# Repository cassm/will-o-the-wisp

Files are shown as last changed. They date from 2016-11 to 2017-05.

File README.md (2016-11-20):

Will-o-the-wisp
===============

60 4-channel (rgbww) SK6812 LEDs arranged over 12 pentagonal PCBs in a pentagonal dodecahedron, controlled by a teensy 3.X.
---------------------------------------------

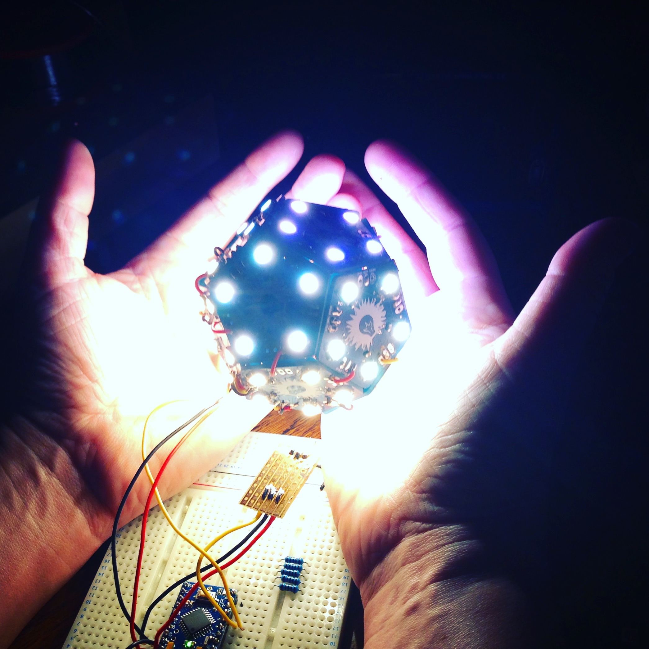
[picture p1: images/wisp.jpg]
Hands for scale Assembled example

[Photo Credit: Dee Ruane](https://www.instagram.com/everythinglightsup/)

Assembly notes:
--------------

- Each PCB has one input port and four output ports. Obviously the order and orientation in which they are wired up is critical, as co-ordinate calculation is done by static array lookup. I have not yet produced a set of instructions which represent how to assemble them in the order assumed by the software.

- I strongly advise against trying to get the firmware to compile on an arduino, as the full firmware relies on several large lookup tables being kept in memory. The code is written on the assumption that it will be run on something with at least as much capacity as a teensy 3

- You may notice that the current version of the PCBs have 6 leds one, rather than the stated 5. This is because I revised the design to give higher resolution for spacial patterns prior to learning that the fadecandy dithering routine supports a maximum of 64 leds in a string, and I have the intention of hacking in a cut-down version of fadecandy in order to support temporal dithering. However, the 64 pixel limit is a timing constraint, and is based on the assumption of 3 channels. As we are using 4 channels, this may imply a limit of (64*3 / 4 =) 48 LEDs per lantern, unless we split 3 DMA channels over 2 lanterns, which will involve much more wiring and anyway it's all very complicated and I don't want to think about it right now, but that's why.

- note that the Teensy has a logic voltage level of 3v3 and the pixels have a voltage level of 5v. I found that it mostly worked without shifting the logic level, but it was more prone to glitching. For this reason, I recommend the use of a logic level converter.

- When you're testing the module, I strongly recommend using some kind of diffuser, otherwise you'll end up with a bunch of things which look like QR codes in your vision, and that can't be good for you.

- The script which generates the palettes takes R8G8B8 encoded windows bitmaps, and requires python 3, scipy, numpy, and pillow. I intend to shortly add more interpolation options and make it way less hacky.

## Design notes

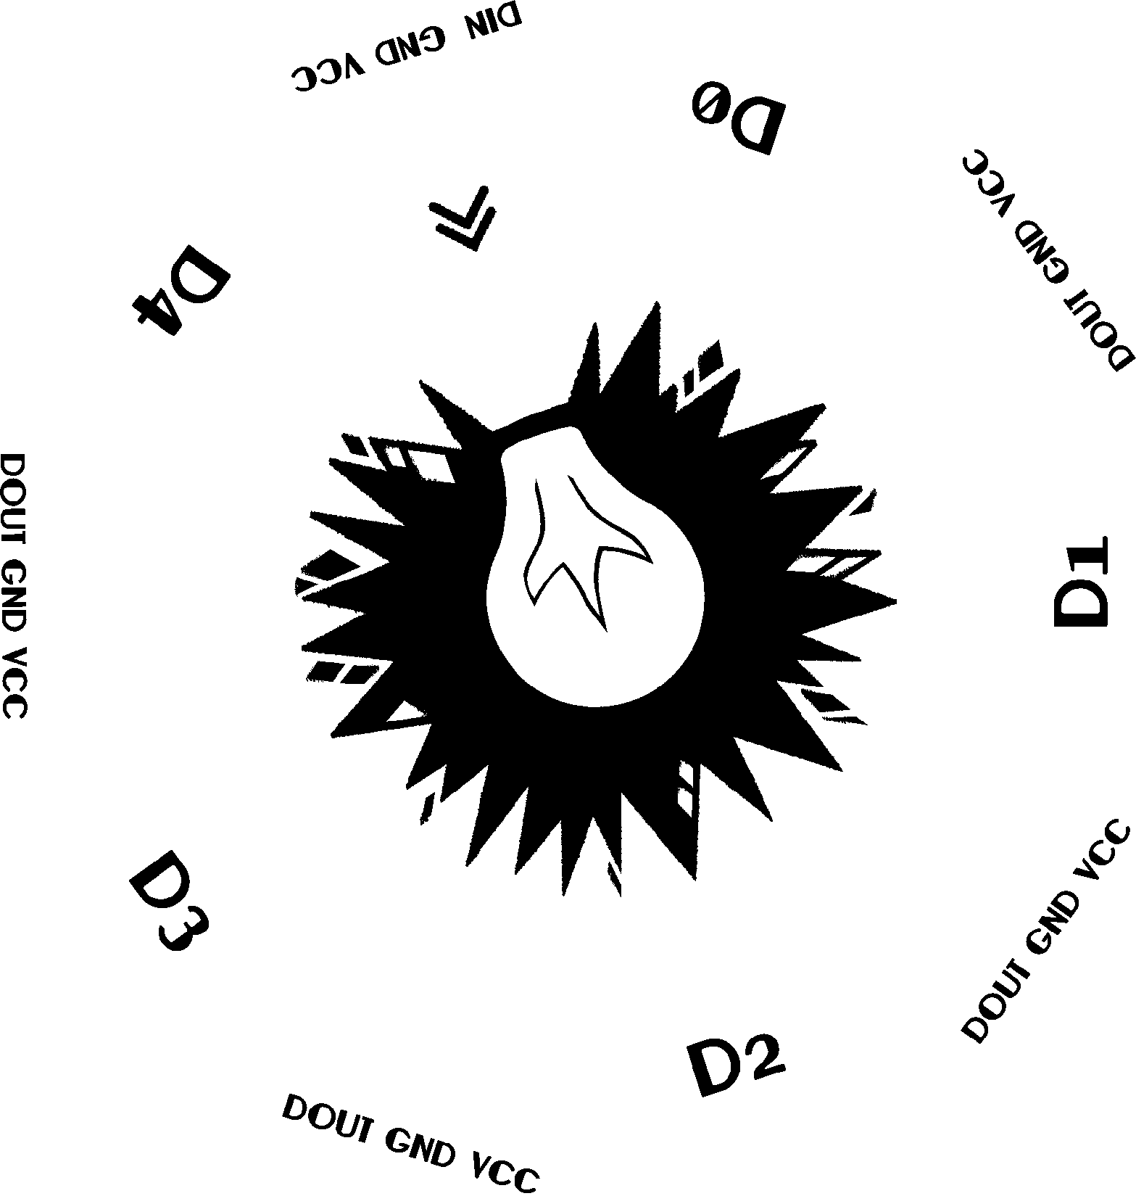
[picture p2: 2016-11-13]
PCB/silkscreen.bmp

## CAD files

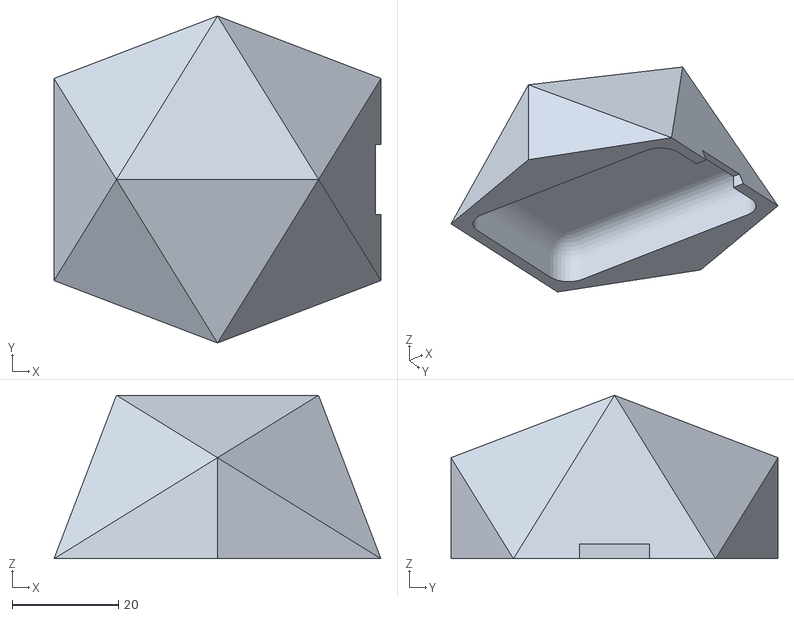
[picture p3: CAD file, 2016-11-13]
3d printing/node.stl
61.5 x 61.5 x 30.7

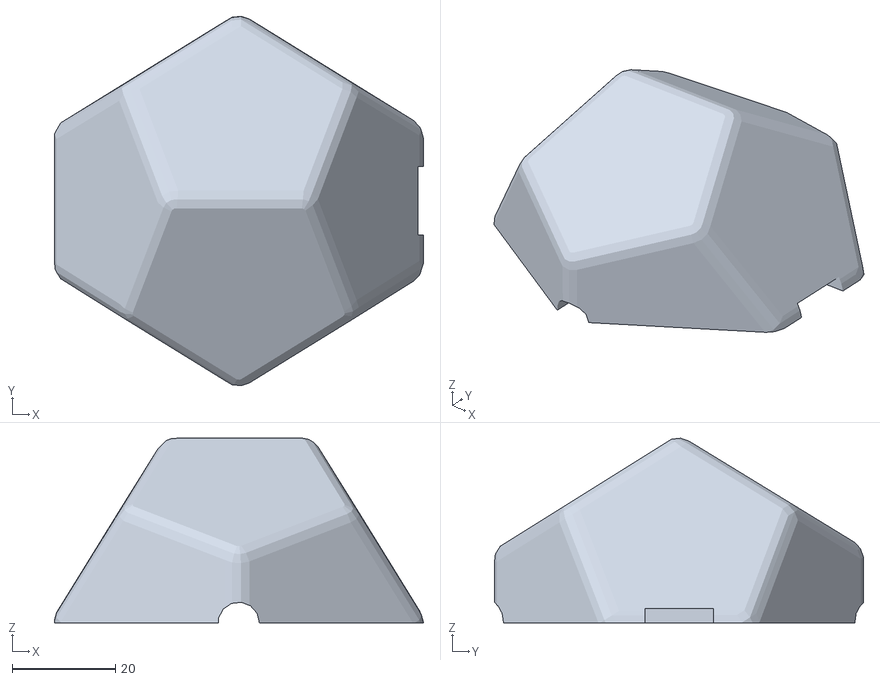
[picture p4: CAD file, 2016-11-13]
3d printing/node_2.stl
71.4 x 71.4 x 35.7

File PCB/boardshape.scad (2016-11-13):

$fa=0.01;
$fs=0.01;

minkowski() {
	polygon([[0,0],[0,1.02362],[0.88661417,0.511811]]);
	circle(0.0787402);
}

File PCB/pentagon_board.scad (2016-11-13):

$fs=0.02;
$fa=0.02;

module triangle(radius)
{
  o=radius/2;		//equivalent to radius*sin(30)
  a=radius*sqrt(3)/2;	//equivalent to radius*cos(30)
  polygon(points=[[-a,-o],[0,radius],[a,-o]],paths=[[0,1,2]]);
}

module reg_polygon(sides,radius)
{
  function dia(r) = sqrt(pow(r*2,2)/2);  //sqrt((r*2^2)/2) if only we had an exponention op
  if(sides<2) square([radius,0]);
  if(sides==3) triangle(radius);
  if(sides==4) square([dia(radius),dia(radius)],center=true);
  if(sides>4) circle(r=radius,$fn=sides);
}

module pentagon(radius)
{
  reg_polygon(5,radius);
}

minkowski() {
	pentagon(0.75);
	circle(0.0787402);
}

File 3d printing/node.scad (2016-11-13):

//include <./Icosahedron-solid.scad>
//$fa=0.1;
//$fs=0.1;

scale = 41;
pinPitch = 2.54;
numPins = 5;
numRows = 2;
headerHeight = 9;
fitGap = 0.5;

holeRadius = 4;

module reg_polygon(sides,radius)
{
  function dia(r) = sqrt(pow(r*2,2)/2);  //sqrt((r*2^2)/2) if only we had an exponention op
  if(sides<2) square([radius,0]);
  if(sides==3) triangle(radius);
  if(sides==4) square([dia(radius),dia(radius)],center=true);
  if(sides>4) circle(r=radius,$fn=sides);
}

module pentagon(radius)
{
  reg_polygon(5,radius);
}

module dodecahedron(height) 
{
    scale([height,height,height]) //scale by height parameter
    {
        intersection()
		  {
            //make a cube
            cube([2,2,1], center = true); 
            intersection_for(i=[0:4]) //loop i from 0 to 4, and intersect results
            { 
                //make a cube, rotate it 116.565 degrees around the X axis,
                //then 72*i around the Z axis
                rotate([0,0,72*i])
                rotate([116.565,0,0])
                cube([2,2,1], center = true); 
            }
        }
    }
}



//scale(scale) show_solid(solid_1);

difference() {
	 rotate([32, 0, 0]) {
	 	  minkowski() {
		  	   dodecahedron(54);
    	      //scale(scale) show_solid(solid_1);
		      sphere(4);
		  }
	 }
    translate([10,0,-1.5*scale])
        cube(scale*3, true);
    arduinoSpace();
    translate([scale - headerHeight, 0, 0])
        cube([headerHeight, numPins*pinPitch + fitGap, numRows*pinPitch + fitGap],true);
	 rotate([90,0,0])
	     cylinder(scale*2,holeRadius,holeRadius,true);
}

module arduinoSpace() {
    minkowski() {
        cube([48,26,10],true);
        sphere(5);
    }
}

/*rotate([0,0,180]) {
translate([-27,0,17]) {
rotate([0,-58,0]) {
color("blue") {
    minkowski() {
	     pentagon(0.75*25.4);
	     circle(0.0787402*25.4);
    }
}
}}}*/

/*translate([0,0,scale*0.77])
    rotate([0,0,0])
        color("gray")
            linear_extrude(1)
                circle(d=scale, true);
*/

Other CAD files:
PCB/pentagon_board_guides.scad

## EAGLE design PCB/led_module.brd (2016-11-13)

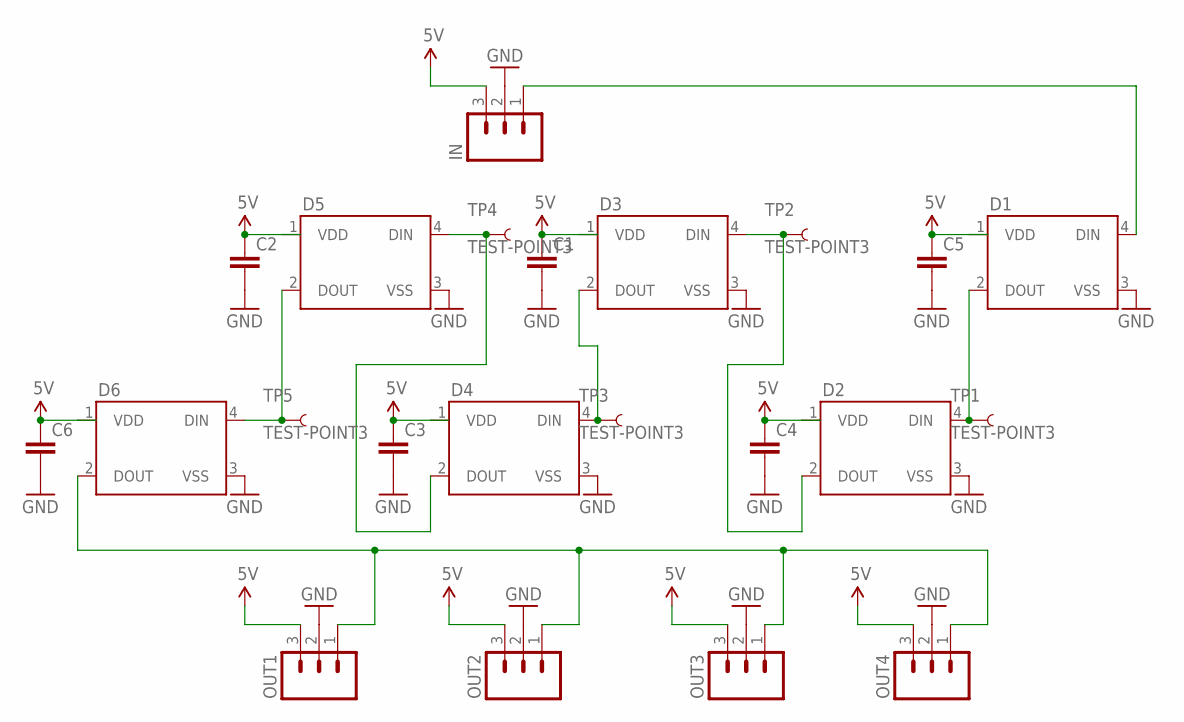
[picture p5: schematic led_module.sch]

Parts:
C1, C2, C3, C4, C5, C6: CAP0805; 0805
D1, D2, D3, D4, D5, D6: WS2812B
IN: M03LONGPADS; 1X03_LONGPADS
OUT1, OUT2, OUT3, OUT4: M03LONGPADS; 1X03_LONGPADS
TP1, TP2, TP3, TP4, TP5: TEST-POINT3; PAD.03X.03

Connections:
5V: C1.1, C2.1, C3.1, C4.1, C5.1, C6.1, D1.1 (VDD), D2.1 (VDD), D3.1 (VDD), D4.1 (VDD), D5.1 (VDD), D6.1 (VDD), IN.3, OUT1.3, OUT2.3, OUT3.3, OUT4.3
GND: C1.2, C2.2, C3.2, C4.2, C5.2, C6.2, D1.3 (VSS), D2.3 (VSS), D3.3 (VSS), D4.3 (VSS), D5.3 (VSS), D6.3 (VSS), IN.2, OUT1.2, OUT2.2, OUT3.2, OUT4.2
unnamed: D1.4 (DIN), IN.1
unnamed: D4.2 (DOUT), D5.4 (DIN), TP4.P$1
unnamed: D5.2 (DOUT), D6.4 (DIN), TP5.P$1
unnamed: D3.2 (DOUT), D4.4 (DIN), TP3.P$1
unnamed: D2.2 (DOUT), D3.4 (DIN), TP2.P$1
unnamed: D6.2 (DOUT), OUT1.1, OUT2.1, OUT3.1, OUT4.1
unnamed: D1.2 (DOUT), D2.4 (DIN), TP1.P$1

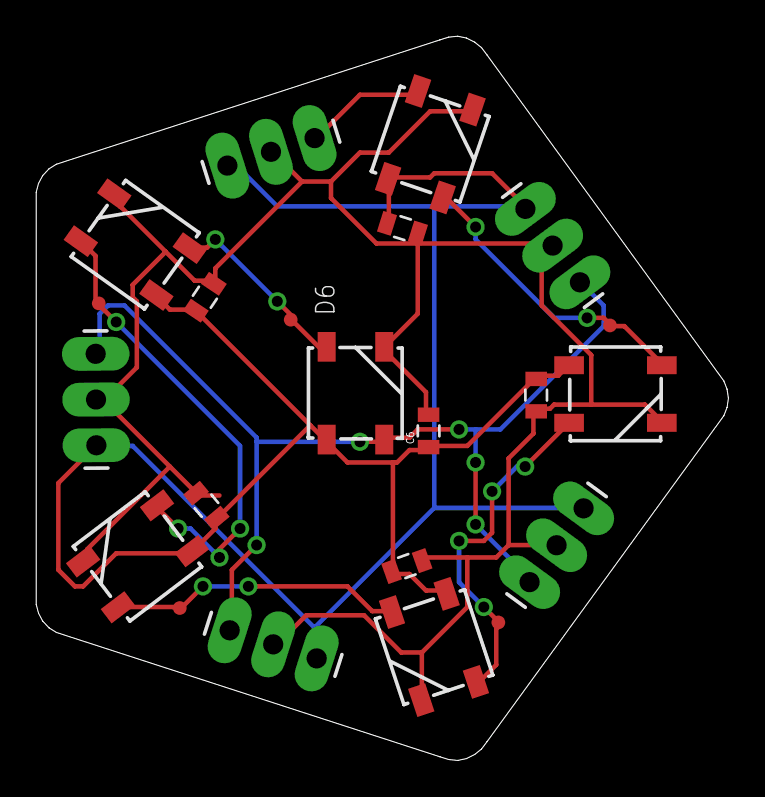
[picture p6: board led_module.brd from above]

Board: 2 copper layers, 38.5 x 40.2 mm, 22 parts (0 on the bottom side), 9 nets.

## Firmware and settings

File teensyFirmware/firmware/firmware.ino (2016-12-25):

#include <math.h>
#include <stdint.h>
#include <avr/io.h>
#include <avr/interrupt.h>
#include "OctoSK6812.h"
#include "modulationFuncs.h"
#include "paletteSampler.h"
#include "correction.h"
#include "coords.h"
#include <cmath>

#include "unicornBarf_palette.h"
#include "stressTest_palette.h"
#include "fire_palette.h"

////////////// CONFIG SECTION ///////////////

#define BRIGHTNESS_POT   0
#define SERIAL_COMMANDS  1
#define FORM_FACTOR      TUBE

#define modeSwitchPin 23
#define analogueBrightnessPin 8

/////////////////////////////////////////////

const int ledsPerStrip = 31;
double speedFactor = 0.5;
volatile int patternNumber = 0;
long long unsigned int lastDebounceTime = 0;
int debounceInterval = 200;
float brightnessVal = 512;
int on = 1;
bool awaitingBrightnessVal = false;
bool awaitingSpeedVal = false;

long long unsigned int iteration;

int drawingMemory0[ledsPerStrip*8];
int drawingMemory1[ledsPerStrip*8];
DMAMEM int displayMemory[ledsPerStrip*8];

OctoSK6812 strip(ledsPerStrip, displayMemory, drawingMemory0, drawingMemory1, SK6812_GRBW);

uint16_t rgbwVals[ledsPerStrip][4] = { { 0 } };

void patternChangeIsr () {
    Serial.println("INTERRUPT");
    long long unsigned int currentTime = millis();
    if (currentTime < (lastDebounceTime + debounceInterval)) {
        return;
    }
    lastDebounceTime = currentTime;

    patternNumber++;
    if (patternNumber > 4) {
        patternNumber = 0;
    }
}

void setup() {
  Serial.begin(38400);
  strip.begin(); // This initializes the NeoPixel library.
  strip.show(0); // Initialize all pixels to 'off'

  pinMode(modeSwitchPin, INPUT); // sets the digital pin as output
  attachInterrupt(modeSwitchPin, patternChangeIsr, RISING);

  iteration = 0;
  delay(500);
}

void processSerialInput (uint8_t opcode) {
    if (awaitingBrightnessVal) {
        brightnessVal = opcode * 4; // convert to 10 bit
        awaitingBrightnessVal = false;
        return;
    }

    if (awaitingSpeedVal) {
        speedFactor = (float)255/opcode;
        awaitingSpeedVal = false;
        return;
    }

    switch (opcode) {
        default: break; // ignore unrecognised characters

        case ('b'): awaitingBrightnessVal = true;
                    break;

        case ('s'): awaitingSpeedVal = true;
                    break;

        case ('F'): patternNumber = 0; // fire
                    break;

        case ('R'): patternNumber = 1; // rain
                    break;

        case ('S'): patternNumber = 2; // star drive
                    break;

        case ('U'): patternNumber = 3; // unicorn Barf
                    break;

        case ('T'): patternNumber = 4; // stress test
                    break;

        case ('O'): on = !on; // toggle on/off
                    break;
    }
}

void starDrive (uint16_t pixel[4], double pixelPosition, const uint16_t palette[][4], int paletteLength) {
    uint16_t sampleVal[4];
    double paletteMixLevel = sin(pixelPosition+iteration*speedFactor*0.05 - 0.5) + 1;

    getPaletteSample(palette, paletteLength, (speedFactor * iteration), sampleVal, true, false);

    pixel[0] = (paletteMixLevel * sampleVal[0] / 2);
    pixel[1] = (paletteMixLevel * sampleVal[1] / 2);
    pixel[2] = (paletteMixLevel * sampleVal[2] / 2);
    pixel[3] = (((sin(pixelPosition+iteration*speedFactor*0.05) + 1) * 0.75 + 0.25) * 511);
}

void loop() {
    int i;
    uint16_t rainSetPoint[] = {256, 0, 0, 256};
    uint16_t outputVal[4];
    float fireIndex, sinOffset;
    int fireOffset;

    iteration++;

#if SERIAL_COMMANDS
    if (Serial.peek() != -1) {
        processSerialInput(Serial.read());
    }
#endif

#if BRIGHTNESS_POT
    float val = analogRead(analogueBrightnessPin);
    brightnessVal = 7*(brightnessVal/8) + (val/8); // smooth values
#endif

    if (!on) {
        for (i = 0; i < ledsPerStrip; i++) {
            for (int j = 0; j < 4; j++) {
                rgbwVals[i][j] = 0;
            }
            strip.setPixel(i, 0, 0, 0, 0, 0);
        }

        strip.show(0);
        while (!on) {
            delay (200); // check 5 times a second
#if SERIAL_COMMANDS
            if (Serial.peek() != -1) {
                processSerialInput(Serial.read());
            }
#endif
        }
    }

    switch (patternNumber) {
    default:
    case 0: if (randomIntervalTimer(1)) { // Fire simulation
                i = random() % ledsPerStrip;
                fireIndex = (firePaletteLen / 2) + (getCylindricalX(i) * firePaletteLen / 2);

                fireOffset = 0;
                for (int j = 0; j < 8; j++) {
                    fireOffset += random() % (firePaletteLen/44);
                }
                fireOffset -= firePaletteLen/11;

                fireIndex += (fireOffset);
                if (fireIndex < 0) {
                    fireIndex = 0;
                }
                if (fireIndex > firePaletteLen-1) {
                    fireIndex = firePaletteLen-1;
                }

                for (int j = 0; j < 4; j++) {
                    rgbwVals[i][j] = fireRgbwPalette[((int)(fireIndex)%firePaletteLen)][j];
                }
            }

            sinOffset = (sin(iteration*0.05)+sin(iteration*0.11)/4) * firePaletteLen/16;

            for (i = 0; i < ledsPerStrip; i++) {
                fireIndex = (firePaletteLen / 2) + (getCylindricalX(i) * firePaletteLen / 2)+sinOffset;

                while (fireIndex < 0) {
                    fireIndex += firePaletteLen;
                }
                while (fireIndex > firePaletteLen-1) {
                    fireIndex -= firePaletteLen;
                }

                fadePixel (rgbwVals[i], fireRgbwPalette[(int)(fireIndex)%firePaletteLen], 6);
                gammaCorrect (rgbwVals[i], outputVal, brightnessVal);
                colourCorrect (outputVal);
                strip.setPixel(i, outputVal, 0);
            }

            strip.show(0);
            break;

    case 1: if (randomIntervalTimer(1000)) { // Rain
                int pixel = random() % ledsPerStrip;

                for (int i = 0; i < 4; i++) {
                    rgbwVals[pixel][i] = unicornBarfRgbwPalette[(int)(iteration*speedFactor*0.05)%unicornBarfPaletteLen][i];
                }
            }

            for (i = 0; i < ledsPerStrip; i++) {
                fadePixel (rgbwVals[i], rainSetPoint, 3);
                gammaCorrect (rgbwVals[i], outputVal, brightnessVal);
                colourCorrect (outputVal);
                strip.setPixel(i, outputVal, 0);
            }

            strip.show(0);
            break;

    case 2: for (i = 0; i < ledsPerStrip; i++) { // Star drive
                uint16_t starDriveVal[4];

                starDrive(starDriveVal, -1*getCylindricalX(i), unicornBarfRgbwPalette, unicornBarfPaletteLen);

                fadePixel (rgbwVals[i], starDriveVal, 3);
                gammaCorrect (rgbwVals[i], outputVal, brightnessVal);
                colourCorrect (outputVal);
                strip.setPixel(i, outputVal, 0);
                strip.setPixel(i, outputVal, 1);
            }

            strip.show(0);
            break;

    case 3: for (i = 0; i < ledsPerStrip; i++) { // Stress test palette
                uint16_t stressTestVal[4];

                getPaletteSample(stressTestRgbwPalette, stressTestPaletteLen, getCylindricalX(i)*2 + (speedFactor * iteration), stressTestVal, true, false);

                fadePixel (rgbwVals[i], stressTestVal, 3);
                gammaCorrect (rgbwVals[i], outputVal, brightnessVal);
                colourCorrect (outputVal);
                strip.setPixel(i, outputVal, iteration%2);
            }

            strip.dither(iteration%2); // allows richer colour represenation
            break;

    case 4: for (i = 0; i < ledsPerStrip; i++) { // Unicorn Barf palette
                uint16_t unicornBarfVal[4];
                getPaletteSample(unicornBarfRgbwPalette, unicornBarfPaletteLen, getCylindricalX(i)*2 + (speedFactor * iteration), unicornBarfVal, true, false);

                fadePixel (rgbwVals[i], unicornBarfVal, 3);

                gammaCorrect (rgbwVals[i], outputVal, brightnessVal);
                colourCorrect (outputVal);
                strip.setPixel(i, outputVal, iteration%2);
            }

            strip.dither(iteration%2);
            break;
    }
}

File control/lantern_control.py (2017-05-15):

#!/usr/bin/env python

from __future__ import print_function
from __future__ import division
import time
import math
import glob
import random
from PIL import Image
from operator import add
import atexit
import serial
import sys
import os
import rgbw_utils
import colours

# add openpixel python path
cwd = os.getcwd()
sys.path.insert(0, cwd + "/openpixelcontrol/python")

import opc
import color_utils

# generate coordinates
execfile("coordGen.py")
import coords

running_on_pi = os.uname()[4][:3] == 'arm'

if running_on_pi:
    import RPi.GPIO as GPIO

    # set up GPIO
    GPIO.setmode(GPIO.BOARD)
    GPIO.setup(11, GPIO.IN, pull_up_down=GPIO.PUD_UP)
    GPIO.setup(13, GPIO.IN, pull_up_down=GPIO.PUD_UP)
    GPIO.setup(15, GPIO.IN, pull_up_down=GPIO.PUD_UP)
    GPIO.setup(12, GPIO.IN, pull_up_down=GPIO.PUD_UP)
    GPIO.setup(33, GPIO.IN, pull_up_down=GPIO.PUD_UP)
    GPIO.setup(31, GPIO.IN, pull_up_down=GPIO.PUD_UP)
    GPIO.setup(29, GPIO.IN, pull_up_down=GPIO.PUD_UP)
    GPIO.setup(18, GPIO.IN, pull_up_down=GPIO.PUD_UP)
    GPIO.setup(16, GPIO.IN, pull_up_down=GPIO.PUD_UP)
    GPIO.setup(37, GPIO.IN, pull_up_down=GPIO.PUD_UP)
    GPIO.setup(36, GPIO.IN, pull_up_down=GPIO.PUD_UP)
    GPIO.setup(32, GPIO.IN, pull_up_down=GPIO.PUD_UP)
    GPIO.setup(22, GPIO.IN, pull_up_down=GPIO.PUD_UP)


@atexit.register
def cleanup():
    if running_on_pi:
        GPIO.cleanup()
    else:
        pass

# allow manipulation of time through potentiometer
last_measured_time = time.time()
effective_time = time.time()

last_mode_switch = time.time()
auto_mode_interval = 300  # 5 minutes

colour_correction_factor = [0.7, 0.8, 1.0, 1.0]
# colour_correction_factor = [1, 1, 1.0, 1.0]

simulate = not running_on_pi

serial_initialised = False
srl_speed_val = 512
srl_brightness_val = 512

srl_r_val = 512
srl_g_val = 512
srl_b_val = 512
srl_w_val = 512

try:
    srl = serial.Serial("/dev/ttyACM0",
                        baudrate=57600,
                        parity=serial.PARITY_NONE,
                        stopbits=serial.STOPBITS_ONE,
                        bytesize=serial.EIGHTBITS,
                        writeTimeout=0,
                        timeout=10,
                        rtscts=False,
                        dsrdtr=False,
                        xonxoff=False)

    if srl.isOpen():
        serial_initialised = True

except Exception as e:
    pass

# grab palettes
palettePath = cwd + "/../palettes/"
paletteExtension = ".bmp"
paletteFiles = glob.glob(palettePath + "*" + paletteExtension)

paletteNames = list((fileName[len(palettePath):-len(paletteExtension)], fileName) for fileName in paletteFiles)
palettes = {}

auto_palette = "auto"
manual_palette = "manual"

for title, path in paletteNames:
    im = Image.open(path, "r")
    width, height = im.size
    rgbwVals = []
    for pixel in range(width):
        r, g, b = im.getpixel((pixel, 0))
        w = min((r, g, b))
        rgbwVals.append((g - w, r - w, b - w, w))
    palettes[title] = rgbwVals

palettes[manual_palette] = []

# -------------------------------------------------------------------------------
# handle command line

if len(sys.argv) == 1:
    if running_on_pi:
        IP_PORT = '127.0.0.1:7890'
    else:
        IP_PORT = '127.0.0.1:22368'
elif len(sys.argv) == 2 and ':' in sys.argv[1] and not sys.argv[1].startswith('-'):
    IP_PORT = sys.argv[1]
else:
    print('''
Usage: lantern_control.py [ip:port]

If not set, ip:port defaults to 127.0.0.1:7890
''')
    sys.exit(0)

# -------------------------------------------------------------------------------
# connect to server

client = opc.Client(IP_PORT)
if client.can_connect():
    print('    connected to %s' % IP_PORT)
else:
    # can't connect, but keep running in case the server appears later
    print('    WARNING: could not connect to %s' % IP_PORT)
print('')

# -------------------------------------------------------------------------------
# send pixels

print('    sending pixels forever (control-c to exit)...')
print('')

pixels_per_lantern = 60
n_lanterns = len(coords.local_cartesian)
n_pixels = pixels_per_lantern * n_lanterns  # 60 leds per lantern
print("num lanterns = " + str(n_lanterns))
print("num LEDs = " + str(n_pixels))

buffer_size = rgbw_utils.get_buffer_size(n_pixels)

if simulate:
    buffer_size = n_pixels

fps = 60  # frames per second

pixel_buffer = [[0.0, 0.0, 0.0] for i in range(buffer_size)]
last_raindrops = [(0.0, 0.0, 0.0, 0.0, 0.0) for drop in range(n_pixels)]

random_values0 = [random.random() for ii in range(n_pixels)]
random_values1 = [random.random() for ii in range(n_pixels)]
random_values2 = [random.random() for ii in range(n_pixels)]
random_values3 = [random.random() for ii in range(n_pixels)]
random_values4 = [random.random() for ii in range(n_pixels)]
random_values5 = [random.random() for ii in range(n_pixels)]
random_values6 = [random.random() for ii in range(n_pixels)]


def inverse_square(x, y, exponent):
    return 1.0 / max(abs(x - y) ** exponent, 0.001)

def get_pixel_colour(ii, auto):
    if auto:
        time_factor = 5
        return palettes[auto_palette][int((effective_time * time_factor + coords.origin_delta[ii]) % len(palettes[auto_palette]))]
    else:
        pixel_index = int(coords.origin_delta[ii] * 100)

        if pixel_index < len(palettes[manual_palette]):
            return palettes[manual_palette][pixel_index]
        elif len(palettes[manual_palette]) > 0:
            return palettes[manual_palette][-1]
        else:
            return (0, 0, 0, 0)

def colour_smooth(pixels, auto):
    for ii in range(n_pixels):
        rgbw_val = get_pixel_colour(ii, auto)
        rgbw_utils.set_pixel(pixels, ii, rgbw_val, simulate, invert)

def colour_waves(pixels, time_factor, space_factor, auto):
    for ii in range(n_pixels):
        # gamma correct
        sin_level = (math.sin(effective_time*time_factor + origin_delta[ii]*space_factor)/3 + 0.66) ** 2.2
        # rgbw_val = (255*sin_level for i in range(4))
        rgbw_val = list(channel * sin_level for channel in get_pixel_colour(ii, auto))
        rgbw_utils.set_pixel(pixels, ii, rgbw_val, simulate, invert)
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

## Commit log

2016-11-13 Discovered the correct spelling of "palette"
    [OctoSK6812.cpp, firmware.ino]
2016-11-19 Implement temporal dithering in octosk6812 library
    This algorithm still relies on copying the buffer for each frame, which is slower than I'd like. Plan to implement a zero copy variant later
2016-11-19 Make gamma correction and interpolation optional in palette sampler funcs
2016-11-23 Add interrupt on pin 23 for changing patterns with a button
2016-11-23 Remove trailing whitespace (thanks, arduino ide)
2016-11-23 Add debounce interval to button isr
2016-12-24 Add fire palette, move palette arrays into progmem for compatibility with teensy 3.0
2016-12-25 Move to 64-stage dithering and buffer-swapping variant of LED library
    [OctoSK6812.cpp]
2016-12-25 Big ugly commit.
    Changes include:
    - Added fire pattern algorithm
    - Added config defines
    - Added serial control
    - Added star drive pattern algorithm
    - "Bugfixes and performance enhancements"
    [firmware.ino]
2017-03-26 Move teensy firmware into subdirectory, as we are now using fadecandy
2017-03-26 Add fadecandy layout file
    Due to each lantern having 60 4-channel LEDs, which are equivalent to 80 3-channel leds, we must use two fadecandy lines for each core
2017-03-26 Add coordinates
    The cartesian coordinates are generated from a list of lantern locations and radii. Currently requires all lanterns to have the same rotation, as this can be marked on the core. It may be easier to fix the rotation in software later on
2017-03-27 Add colour correction for green channel in rgbw_utils. Blunt tool but will do for now
    [rgbw_utils.py]
2017-03-27 Fix bug with palette autogeneration
    [lantern_control.py]
2017-03-31 Use new rgbw_utils funcs, autogenerate num_pixels, add several new patterns
    I know this commit msg leaves much to be desired but in my defence I am super tired
2017-04-01 Update fclayout file for 24 line device
2017-04-01 Add pattern increment button
2017-04-02 Add speed control with slaved i2c device
2017-04-02 Add sketch for slaved arduino
2017-04-02 Add interrupts for controls, add sensible failure behaviour for i2c errors
    [lantern_control.py]
2017-04-02 Fix palette handling, add random pattern handling
    [lantern_control.py]
2017-04-03 Improve flare and glitch handling, swap out i2c analog slave for teensy w/ usb serial
    [lantern_control.py]
2017-04-05 Add auto mode, flare on switch
2017-04-06 Replace palette viewer with sky simulator, much fine tuning
    [lantern_control.py]
2017-04-06 Fix auto mode and flare-on-switch
    [lantern_control.py]
2017-04-06 Finalise flame pattern, assign button
2017-04-06 Update last mode switch on manual switch
2017-04-06 Fix bug with auto timer reset
    [lantern_control.py]
2017-04-06 Add unicorn barf (rainbow sparkles) pattern and map to button
2017-04-06 Add glitch option, optimise unicorn barf
    [lantern_control.py, rgbw_utils.py]
2017-05-12 Change glitch function for colour invert function
    [lantern_control.py, rgbw_utils.py]
2017-05-13 Add serial slave device for reading potentiometers
2017-05-13 Add 4 physical sliders to console
    Also replace unicorn barf pattern, which was a bit of a bodge, with the physical rgbw controls
    [lantern_control.py]
2017-05-13 Add gamma correction on sliders, and invert range to account for wiring
    [lantern_control.py]
2017-05-13 Correct bounds on pot reads
    [lantern_control.py]
2017-05-13 Reset lantern orientations, remove fudge factor caused by moving the origina lantern at rumpus
    [coordGen.py]
2017-05-14 Add auto colour (actually a really long palette) and replace flare button with switch for that
    [lantern_control.py]
2017-05-14 Fix colour inversion transformation
    [rgbw_utils.py]
2017-05-15 Add colour correction, retune time factor for new palette len, cut down unnecessary operations, start on smooth after all
    [lantern_control.py]

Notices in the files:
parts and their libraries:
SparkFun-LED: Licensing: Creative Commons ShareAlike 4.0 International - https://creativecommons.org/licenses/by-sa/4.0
